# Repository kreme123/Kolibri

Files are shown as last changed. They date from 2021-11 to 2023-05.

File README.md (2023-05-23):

# Kolibri

Kolibri is Alice-style keyboard with arrow cluster and rotary encoder support.
- Uses Elite-C and THT diodes
- Pcb gasket mount
- Pcb foam using 4mm Eva
- FR4 plate
- Stacked acrylic case
- Rgb underglow

<a href="https://imgur.com/d0MEZ7v">source: imgur.com</a>

<a href="https://imgur.com/5kfvzkP">source: imgur.com</a>

<a href="https://imgur.com/DSsTqab">source: imgur.com</a>

<a href="https://imgur.com/aIfa4iq">source: imgur.com</a>

https://user-images.githubusercontent.com/85822364/146816422-3a67405c-12d5-41d8-b46e-2cc472c4dc81.mp4

### Default Layout
<a href="https://imgur.com/xrApOlS">source: imgur.com</a>
> View on [Keyboard Layout Editor](http://www.keyboard-layout-editor.com/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'&_w:2.25%3B&=Enter%3B&@_x:0.25&w:2.25%3B&=Shift&=Z&_x:9.45%3B&=%3E%0A.&=%3F%0A%2F%2F&_w:1.75%3B&=Shift%3B&@_y:-0.75&x:16.95%3B&=%E2%86%91%3B&@_y:-0.25&x:0.25&w:1.5%3B&=Ctrl&_x:12.45&w:1.5%3B&=Ctrl%3B&@_y:-0.75&x:15.95%3B&=%E2%86%90&=%E2%86%93&=%E2%86%92%3B&@_r:12&y:-6.1&x:5.3%3B&=$%0A4%3B&@_y:-1.0000000000000004&x:6.3%3B&=%25%0A5%3B&@_y:-0.9999999999999999&x:7.3%3B&=%5E%0A6%3B&@_y:-0.9999999999999996&x:4.3%3B&=%23%0A3%3B&@_y:-4.440892098500626e-16&x:3.8%3B&=W&=E&=R&=T%3B&@_x:4.05%3B&=S&=D&=F&=G%3B&@_x:4.55%3B&=X&=C&=V&=B%3B&@_x:4.55&w:1.5%3B&=Alt&_w:2%3B&=Space&=Fn%3B&@_r:-12&y:-1.5500000000000003&x:8.25%3B&=%2F&%0A7&=*%0A8&=(%0A9&=)%0A0%3B&@_x:7.75%3B&=Y&=U&=I&=O%3B&@_x:8%3B&=H&=J&=K&=L%3B&@_x:7.5%3B&=B&=N&=M&=%3C%0A,%3B&@_x:7.5&w:2.75%3B&=Space&_w:1.5%3B&=Alt)

[Gallery](Gallery.md)

[Build guide](Build%20%20guide.md)

[Firmware](Firmware)

Pictures taken by [pl4ntd4ddy](https://www.instagram.com/pl4ntd4ddy/)

(https://www.paypal.com/donate/?hosted_button_id=BAEE2KMJAVYBW)

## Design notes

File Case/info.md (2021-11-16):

Use these files to laser cut your case. All layers use 3mm thick acrylic.

Case in the pictures uses frosted acrylic on top and bottom layer, everything else is clear acrylic.

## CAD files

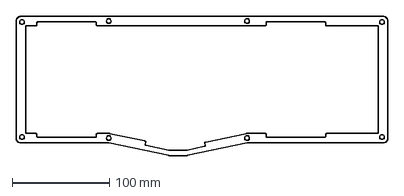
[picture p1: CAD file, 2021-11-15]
Case/02 Case gasket no usb.dxf
381.4 x 142.8 mm

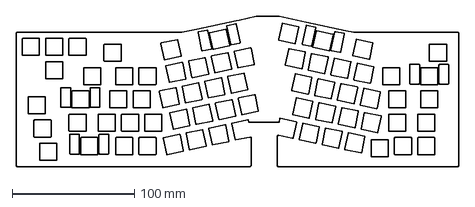
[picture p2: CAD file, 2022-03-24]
Kolibri plate 14mm holes (not tested but should work).dxf
361.4 x 122.6 mm

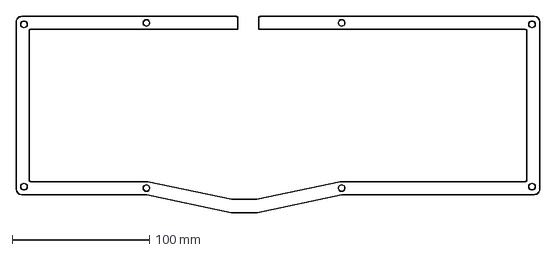
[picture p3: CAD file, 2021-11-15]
Case/05 Case edges.dxf
381.4 x 142.8 mm

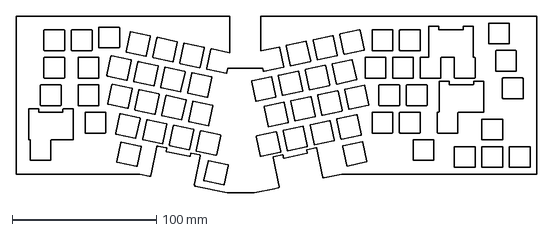
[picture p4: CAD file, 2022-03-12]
Kolibri plate (14.4mm holes).dxf
361.4 x 122.6 mm

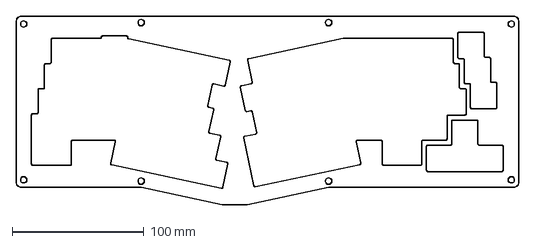
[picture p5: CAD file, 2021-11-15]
Case/06 Case top 1.dxf
381.4 x 142.8 mm

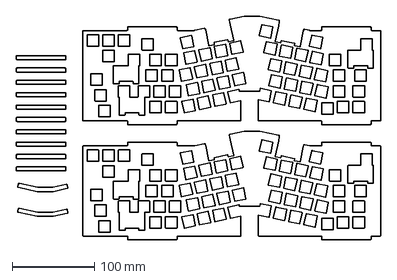
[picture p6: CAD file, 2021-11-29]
Pcb foam and gaskets 0.5mm kerf x2.dxf
442.2 x 271.7 mm

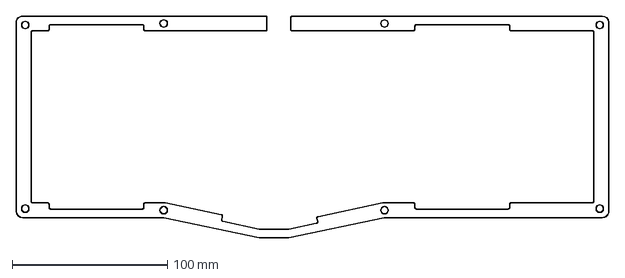
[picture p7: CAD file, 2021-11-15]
Case/04 Case gasket.dxf
381.4 x 142.8 mm

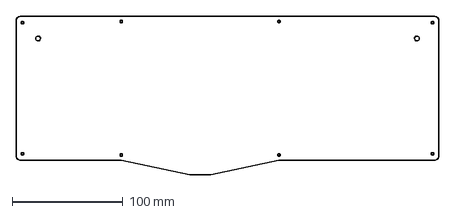
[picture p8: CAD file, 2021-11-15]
Case/01 Case bottom.dxf
381.4 x 142.8 mm

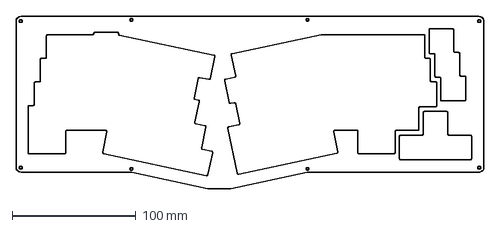
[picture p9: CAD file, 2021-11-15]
Case/07 Case top 2.dxf
377.4 x 138.8 mm

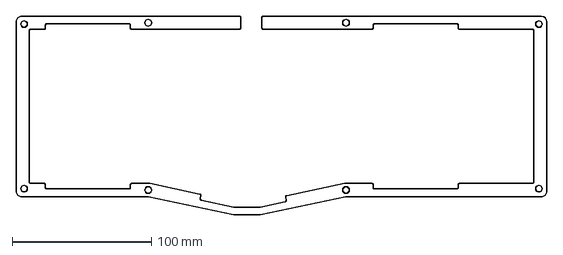
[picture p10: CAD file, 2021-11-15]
Case/03 Case gasket.dxf
381.4 x 142.8 mm

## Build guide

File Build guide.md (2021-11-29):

# Build guide

## Materials
- 16 x [M2x8mm screws](https://www.aliexpress.com/item/32870342767.html?spm=a2g0s.9042311.0.0.52114c4dn6suyl)
- 8 x [M2x12mm standoffs](https://www.aliexpress.com/item/1005001478301407.html?spm=a2g0s.9042311.0.0.52114c4dn6suyl)
- ~70 [1N4148 diodes](https://www.aliexpress.com/item/2025724181.html?spm=a2g0s.9042311.0.0.52114c4d259Ayp)
- [EC11 rotary encoder](https://www.aliexpress.com/item/10000056483250.html?spm=a2g0s.9042311.0.0.52114c4dn6suyl)
- [Silicone rubber feet](https://www.aliexpress.com/item/4000439059508.html?spm=a2g0s.9042311.0.0.52114c4dn6suyl)
- [Aluminum feet](https://www.aliexpress.com/item/32947889825.html?spm=a2g0s.9042311.0.0.52114c4dn6suyl)
- [WS2812B led strip](https://www.aliexpress.com/item/32682015405.html?spm=a2g0s.9042311.0.0.52114c4dn6suyl) 60 IP30 (16 leds on one kolibri) 
- [Double sided tape for feet](https://www.aliexpress.com/item/1005001401843627.html?spm=a2g0s.9042311.0.0.52114c4dn6suyl) round 20mm
- [Elite-C](https://deskthority.net/wiki/Elite-C)

### Also
- Soldering iron and solder
- Phillips screwdriver
- Flush side cutters
- ~70 MX style switches
- 5 PCB mount 2u stabilizers
- Keycaps (check compatibility)

## Building

Connect Elite-C to computer and flash "kolibri_default.hex" firmware using qmk toolbox

Solder diodes for all keys. Black stripe on diode to square pad on pcb
<a href="https://imgur.com/B3Za0va">source: imgur.com</a>

Solder Elite-C to top side of pcb. Check that pins match. Cut off the excess legs. 
I suggest wearing eye protection and placing something to top of Elite-C when cutting excess legs. Those legs will fly.
<a href="https://imgur.com/3hRq8Ik">source: imgur.com</a>

Add rotary encoder (optional)
<a href="https://imgur.com/TNAs7En">source: imgur.com</a>

Add stabilizers 5x2U, pcb foam and FR4 plate. Check that pcb foam sits nicely and is top of gasket "wings". Place switches and solder them.
<a href="https://imgur.com/5Xc3GtY">source: imgur.com</a>
<a href="https://imgur.com/O1NoN6L">source: imgur.com</a>
<a href="https://imgur.com/JhvSGWG">source: imgur.com</a>

Solder rgb strip (optional). Check that strip is correct way (din on strip matches din text on pcb). Add soldering iron to rgb strip pins and holes at pcb. Place them closely and heat up to connect them
<a href="https://imgur.com/yCE28Dx">source: imgur.com</a>

## Case

Put screws from the bottom and add standoffs. 
<a href="https://imgur.com/UYnJwfV">source: imgur.com</a>

Add legs. I suggest using double sided tape rather than screws for better flex clearance.
<a href="https://imgur.com/Va0qu77">source: imgur.com</a>

Add case layers 2-4 and place gasket strips. Leave out middle strip if you prefer more flex
<a href="https://imgur.com/aQx9FSN">source: imgur.com</a>

Add soldered pcb. There's ~0.5mm clearance between outer sides of pcb and inner sides of case. Use your time to place the pcb so it doesn't hit side of case.
<a href="https://imgur.com/JhvSGWG">source: imgur.com</a>

Add rest of the case layers 5-7 and screw it in.
<a href="https://imgur.com/aYyIyYg">source: imgur.com</a>

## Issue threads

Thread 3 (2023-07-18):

Kicad Files

Wolframme, 2023-07-18:
Hi there, is there any chance the Kicad files could be included with this project?

I have no idea what I'm doing at editing PCBs but I think it would benefit the project to include the Kicad files to make editing the keyboard layout easier instead of modifying from the Gerber files.

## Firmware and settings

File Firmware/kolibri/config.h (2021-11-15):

/* Copyright 2021 REPLACE_WITH_YOUR_NAME
 *
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
 * You should have received a copy of the GNU General Public License
 * along with this program.  If not, see <http://www.gnu.org/licenses/>.
 */

#pragma once

#include "config_common.h"

 /* USB Device descriptor parameter */
#define VENDOR_ID       0xFEED
#define PRODUCT_ID      0x0000
#define DEVICE_VER      0x0001
#define MANUFACTURER    kreme
#define PRODUCT         kolibri

/* key matrix size */
#define MATRIX_ROWS 5
#define MATRIX_COLS 15

/*
 * Keyboard Matrix Assignments
 *
 * Change this to how you wired your keyboard
 * COLS: AVR pins used for columns, left to right
 * ROWS: AVR pins used for rows, top to bottom
 * DIODE_DIRECTION: COL2ROW = COL = Anode (+), ROW = Cathode (-, marked on diode)
 *                  ROW2COL = ROW = Anode (+), COL = Cathode (-, marked on diode)
 *
 */
#define MATRIX_ROW_PINS { C6, D4, D0, D1, D2 }
#define MATRIX_COL_PINS { D7, E6, B4, B5, B7, D5, C7, F0, B6, B2, B3, B1, F7, F6, F5 }

#define DIODE_DIRECTION COL2ROW

#define ENCODERS_PAD_A { B0 }
#define ENCODERS_PAD_B { F4 }
#define ENCODER_RESOLUTION 4
#define ENCODER_DIRECTION_FLIP
#define TAP_CODE_DELAY 10

#define RGB_DI_PIN F1
#ifdef RGB_DI_PIN
#define RGBLED_NUM 16
#define RGBLIGHT_HUE_STEP 8
#define RGBLIGHT_SAT_STEP 8
#define RGBLIGHT_VAL_STEP 8
#define RGBLIGHT_LIMIT_VAL 255 /* The maximum brightness level */
#define RGBLIGHT_SLEEP  /* If defined, the RGB lighting will be switched off when the host goes to sleep */
 /*== all animations enable ==*/
#define RGBLIGHT_ANIMATIONS
// /*== or choose animations ==*/
//     #define RGBLIGHT_EFFECT_BREATHING
//     #define RGBLIGHT_EFFECT_RAINBOW_MOOD
//     #define RGBLIGHT_EFFECT_RAINBOW_SWIRL
//     #define RGBLIGHT_EFFECT_SNAKE
//     #define RGBLIGHT_EFFECT_KNIGHT
//     #define RGBLIGHT_EFFECT_CHRISTMAS
//     #define RGBLIGHT_EFFECT_STATIC_GRADIENT
//     #define RGBLIGHT_EFFECT_RGB_TEST
//     #define RGBLIGHT_EFFECT_ALTERNATING
#endif

// generated by KBFirmware JSON to QMK Parser
// https://noroadsleft.github.io/kbf_qmk_converter/

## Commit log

2021-11-15 Create Case dxf
2021-11-29 Create gerberskolibri
2021-11-29 Create gerbersplate
2021-11-29 Create gerbers

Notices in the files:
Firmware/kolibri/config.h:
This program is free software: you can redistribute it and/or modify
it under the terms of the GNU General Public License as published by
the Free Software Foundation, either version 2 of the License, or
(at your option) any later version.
